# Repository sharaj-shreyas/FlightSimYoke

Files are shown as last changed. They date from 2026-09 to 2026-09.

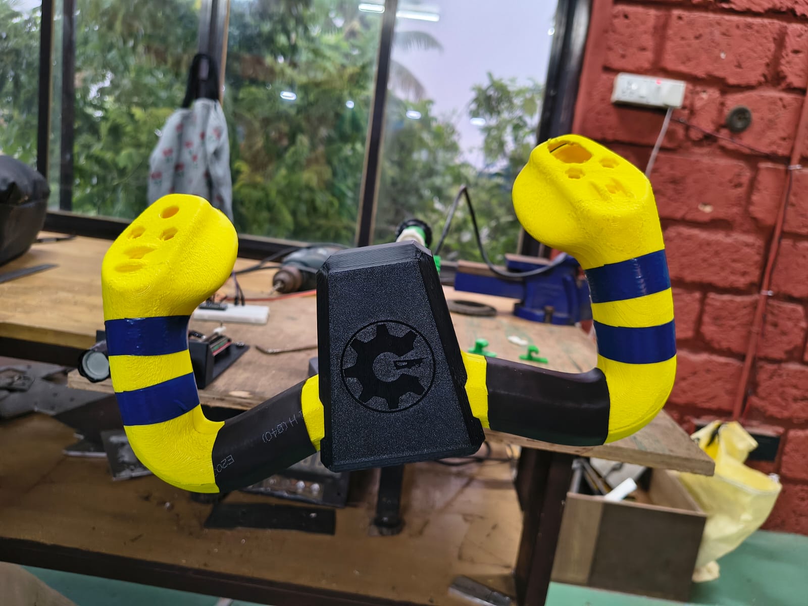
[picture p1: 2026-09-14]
img/2.jpeg

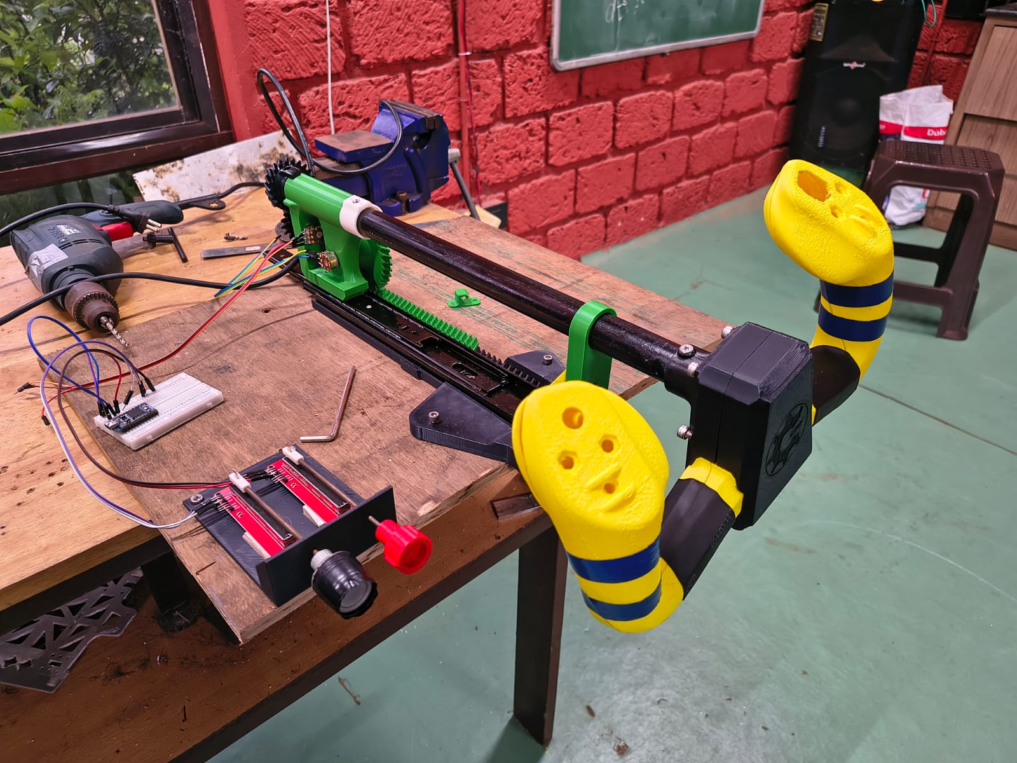
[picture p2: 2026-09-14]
img/1.jpeg

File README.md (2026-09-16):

# FlightSimYoke 
This is a flight simulator yoke and throttle mixture that we designed and built from scratch with some design references from the CadetYoke project.

## Credits - Makerspace Batch of '26
-> Sharaj Shreyas:- Hardware Primary, CAD Primary, Makerspace President, shopping bargainer.
-> Sanath Sanjay Shet:- Software Primary, Slay Queen.
-> Lauren Marian Patrao:- Math genius, emotional support 🤣.

## Read this upto the technical details warning Before doing anything silly with our Project!

## More about the project 
This project started after our JEE exams.. when we were practically jobless and had nothing to do. We came across CadetYokeV2 (https://www.thingiverse.com/thing:4884092), and we knew we had to build this. We started off with a plan to build 4 of these, 1 being the initial version, and then one V2 for the club and one each for Sanath and me. But that did not happen ofc.  We also wanted to build rudder pedal and make the yoke removable and have a steering wheel extension asw but then i had to leave to Gandhinagar 🥀.
When we started printing the files on the bamboo.. we had our first regret. We printed it in the worst setting and worst filament to save time and money but trust me guys, it's not worth it. Anyway, we proceeded with all the building part, and that's when we realised that the printed parts had also warped cuz idiotic me didnt put any supports and rafts. Second regret we went to a hardware shop to buy pipe for the shaft cuz that dude is laurens something and we were expecting a discount. That mf robbed us 🥀. Printing took so much time that we fixed the Creality printer as well, so that we could get things done faster. Fixing the duelmaze and the radiotelescope had already taken too much time and we were far behind schedule. Lauren still had hope that we would finish the pedals, but sadly, we couldn't. Hoping further batches come and fix that as well. 

### Technical Details Warning - Pay attention if you're in charge of setting this up.

## Initial Hardware Setup
1. Firstly, all connections to the Pro Micro need to be made. Check the code for connections
2. Connect the Pro Micro to your computer.
3. Tighten the screws under the green part that slides on the telescopic rails.

## Initial Software setup
1. Once plugged in, the device should show up in Device Manager as a human interface device, specifically a joystick. Do the config for the joystick and choose the axis properly.
2. We don't have a rudder channel, so u can use two keys for now. Or be an expert pilot like me 😜.
3. On MSFS, map the channels to the respective axis and set expo settings (optional).
4. enjoy!

## CAD issues 
1. The throttle and mixture knobs base isn't designed well.. better to redesign
2. Use the adapter for rods given as a separate file (not the one in the throttle+mix file).
3. Try to use exact screws wherever mentioned (Sanath fucking shet just didn't go according to my design)
4. Don't print everything randomly. I have uploaded CAD files with all parts (some are unnecessary and were used for design reference). Check what parts are necessary and then print accordingly. The CAD files also have their edit history with them. Make the best use of them to suit your hardware.

##  Troubleshooting
1. Something broke?? go kys
2. No response usually means loose wires or you've fried the board.
3. Not detecting as a HID device - figure out the driver stuff.
4. If any axis moves backwards in Windows USB Game Controllers (joy.cpl) or MSFS/X-Plane, invert the read value in code (like - FlightYoke.setYAxis(1023 - pitchVal);).

## Requests:
1. Build rudder pedals.
2. Don't break it, the setup is kinda delicate.
3. Think of meaningful upgrades.

## Contributing:
To contribute, make sure to open a branch first, commit there, and then we will review it and merge your pull request.

# Current:
The current code is very basic, and not intended to be the final version as of now, it will, however, be modified over the coming days and will slowly turn into the main source code, after lots of flightsim ofc.

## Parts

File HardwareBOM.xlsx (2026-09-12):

No. | Part | Qty. | Link
1 | M3x16 | 15 | https://onlyscrews.in/products/m3-x-16mm-hex-allen-socket-head-high-tensile12-9-black-anodized-screw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
2 | M3x45 | 8 | https://onlyscrews.in/products/m3-x-45mm-hex-allen-socket-head-high-tensile12-9-black-oxide-screw-dia-3mm-length-45mm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
3 | M5X16 | 8 | https://onlyscrews.in/products/hex-allen-socket-head-m5-x-20?variant=48590709195065
4 | M5X25 | 15 | https://onlyscrews.in/products/m5-x-25mm-hex-allen-socket-head-ss-304-screw?variant=49091478389049
5 | M5X45 | 12 | https://onlyscrews.in/products/m5-x-45mm-hex-allen-socket-head-high-tensile12-9-black-oxide-screw-dia-5mm-length-45mm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
6 | M5X60 | 12 | https://onlyscrews.in/products/m5-x-60mm-hex-allen-socket-head-ss-304-screw-dia-5mm-length-60mm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
7 | M6X20 | 6 | https://onlyscrews.in/products/m6-x-20mm-hex-allen-socket-head-high-tensile12-9-black-oxide-screw-dia-6mm-length-20mm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
8 | M6x45 | 5 | https://onlyscrews.in/products/m6-x-45mm-hex-allen-socket-head-high-tensile12-9-black-oxide-screw-dia-6mm-length-45mm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
9 | M6x120 | 5 | Local
10 | M10x25 | 2 | https://onlyscrews.in/products/m10-x-25mm-hex-allen-socket-head-high-tensile12-9-black-oxide-screw-dia-10mm-length-25mm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
11 | Bearing 625ZZ | 10 | https://onlyscrews.in/products/625-zz-deep-groove-ball-bearing-8x22x7
12 | M3 insert | 15 | https://onlyscrews.in/products/m3-x-5mm-3d-printing-brass-threaded-inserts-dia-3mm-length-5mm
13 | M5 insert | 25 | https://onlyscrews.in/products/m5-x-6mm-brass-threaded-inserts
14 | 3.2 Washers | 30 | http://onlyscrews.in/products/m3-washer-ss304
15 | 5.3 Washers | 30 | https://onlyscrews.in/products/m5-washer-ss304
16 | Nylon nut M3 | 40 | https://onlyscrews.in/products/m3-nyloc-nuts-ss304
17 | Nylon nut M5 | 35 | https://onlyscrews.in/products/m5-nyloc-nuts-ss304
18 | Nylon nut M6 | 15 | https://onlyscrews.in/products/m6-nyloc-nuts-ss304
19 | 608 ZZ Ball Bearing | 8 | https://onlyscrews.in/products/608-zz-deep-groove-ball-bearing-6x17x6
20 | m3X8 | 20 | https://onlyscrews.in/products/hex-allen-csk-m3-x-8-screw-pack-of-20
21 | m4X10 | 5 | https://onlyscrews.in/products/hex-allen-csk-m4-x-10-screw-pack-of-20
22 | m4 NYLOC nuts | 15 | https://onlyscrews.in/products/m4-nyloc-nuts-ss304
23 | M3x8 threaded insert | 10 | https://onlyscrews.in/products/m3-x-8mm-brass-threaded-inserts
24 | m2x4 | 6 | https://onlyscrews.in/products/m2-x-4mm-phillips-round-head-laptop-screw
25 | M2x3 threaded insert | 6 | https://onlyscrews.in/products/m2-x-3mm-brass-threaded-inserts
26 | M3x4 | 10 | https://onlyscrews.in/products/m3-x-8mm-hex-allen-socket-head-high-tensile12-9-black-oxide-screw-dia-3mm-length-8mm
27 | M3x4 threaded insert | 10 | https://onlyscrews.in/products/m4-x-4mm-brass-threaded-inserts
28 | M3x3 threaded insert | 10 | https://onlyscrews.in/products/m3-x-3mm-brass-threaded-inserts
29 | m4x30 | 5 | https://onlyscrews.in/products/m4-x-30mm-hex-allen-csk-ss-304-screw
30 | m3x5 | 15 | https://onlyscrews.in/products/m3-x-5mm-phillips-pan-head-ss-304-screw-dia-3mm-length-5mm
 | M3 Nut | 5
 | M3x8 | 11
 | M4x10 | 3
 | M4 Nut | 8
 | M3x8 Threaded Insert | 6
 | M4x18 | 2
 | M2x4 | 2
 | M2x3 Threaded Insert | 2
 | M3x4 | 6
 | M3x4 Threaded Insert | 8
 | M3x3 Threaded Insert | 6
 | M4x30 | 3
 | M3x5 | 12

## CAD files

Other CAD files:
CAD/Band hook.f3d
CAD/Custom_Guide.f3d
CAD/Throttle+MIX/Throttle +MIX.f3d
CAD/Throttle+MIX/adapter.f3d

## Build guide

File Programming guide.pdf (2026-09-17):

## DuelMaze Programming Guide

### Objectives:

This guide aims to help you with the syntax of C++, and how to program the components being used in the project. These components include the servos, I2C LCD, and the Arduino itself.

### How to use this guide:

The main objective of this guide is to help the members understand what they are going to be working with, and to reduce the time spent on teaching, and utilize it to actually work on the project. Whenever you are stuck on a problem, use this guide first to try and understand the correct way of doing things, and THEN ask one of the UC’s, or your Team Members.

## 1. C++ Syntax:

The language used in Arduino programming is CPP, albeit a more limited version of it. For the scope of this project, we do not need very complicated C++ knowledge. Read the example below to understand how to do basic programming tasks in C++.

### 1.1 Variables and Data Types:

Variables are by far one of the most important parts of programming. Make sure to learn how to use Data Types and variables, because they are fundamental to being able to participate.

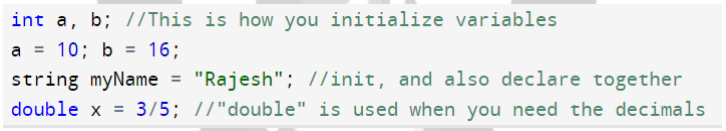
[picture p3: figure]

Notice how in C++, unlike Python, the variables’ data types need to be declared. Also, the variables need not be assigned a value while declaring them, that can be done later as well, as in the case of variables ‘a’ and ‘b’ in our case here. However, the variable ‘myName’ has been declared and given a value at the same time as you can see.

The data type int is used when we want to store an integer(lol), and the string data type is used when we need to store letters, words, etc. the double type, called “floating point” in other languages, is used to store numbers with decimal points in them.
These data types are very important, and will be used during the course of the project.

### 1.2 Flow of Control:

Flow of control is another important aspect of programming, and is almost always the backbone of the program. There are mainly 2 types of flow, namely decisions(if, else) and loops(while, for).

### 1.2.1 IF, ELSE:

If and else statements are used when there is a need to execute only parts of the program, depending on the condition specified. An example is given below:

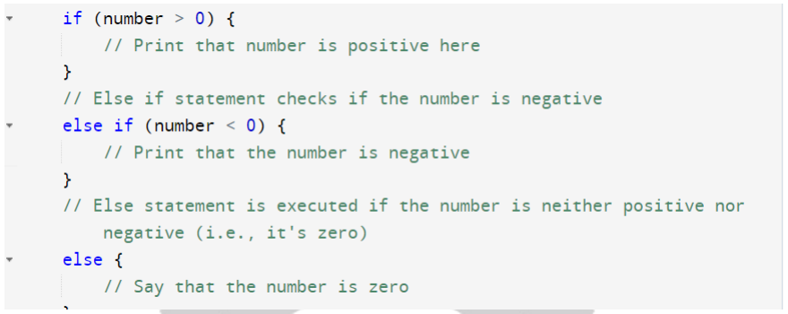
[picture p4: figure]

In this case, we have some variable, number. It’s not necessary to know where this variable comes from, since this is just an example. The code is self explanatory, because of the comments. Now, lets move on to Looping.

### 1.2.2 Looping:

Loops are similar to if and else statements, in the sense that they also check for a condition. The only difference is that instead of executing that particular block of code just once, they do it again and again, until that condition becomes false. There are mainly 3 types of loops in C++, but we’ll only be looking at 2, which are used in all languages. They are: while loops and for loops.

### 1.2.2.1 For loops:

For loops are used, when we know exactly how many times we want to repeat a block of code, or when we want to iterate through a list(this will be discussed later). For example, here, this block of code prints numbers all the way from 1 to 5.

In the code here, notice the syntax of the for loop. First, we declare a control variable, called i, and we give it a value of 1. Then, we tell the loop the condition. In this case, the condition is that i must be less than or equal to 5. The last part is incrementing the value of i. So, in the first iteration(iteration means the same as repetition), the value of i is 1. In the second iteration, it is 2, and so on, until it becomes 5. When the value of i becomes 6, the condition we specified, becomes false, and the loop stops. This is how the output looks.

### 1.2.2.2 While Loops:

While loops are similar to For Loops, in the sense that the code executes based on a control variable, say i. The loop executes till the condition specified is true, and this can be ANY condition, unlike in a for loop, where it only executes based on value. Unlike a for loop, the value of the control variable in this case does not need to change every iteration. This will be more useful in complex programs. Here’s the same program we saw earlier, but written using a while loop.

Now, notice how the syntax is different from a for loop. We declare a variable, i, but outside the loop, and then we only check for the condition when writing the loop. Now, another important thing to notice is that we change(in this case, we are incrementing) the value of i, INSIDE the body of the loop. It is VERY important to make sure that this value changes, orelse the loop will become infinite, which we don't want.

Alright! You’ve just learnt the basics of C++ programming! There are many more topics left, such as arrays, etc. But they’ll be taught to you during the sessions. Now, lets move on to the libraries that we’ll be using in arduino programming, and the structure of an arduino program.

## 2. Arduino Programming:

This second section will cover the Arduino program structure, and the 2 libraries that we’ll be using, which is the LCD-I2C, and the Servo.

### 2.1 Arduino Program Structure:

The basics of arduino programming were taught to you, but lets recap:

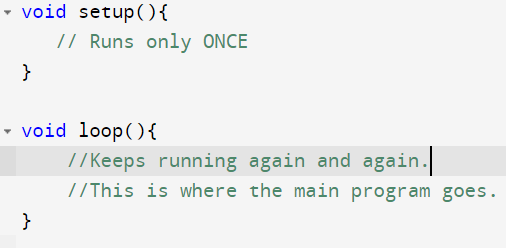
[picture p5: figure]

### 2.2 Servos:

Most of you have already worked with servos in our previous makerspace sessions. In this part, lets go over how to actually turn a servo.

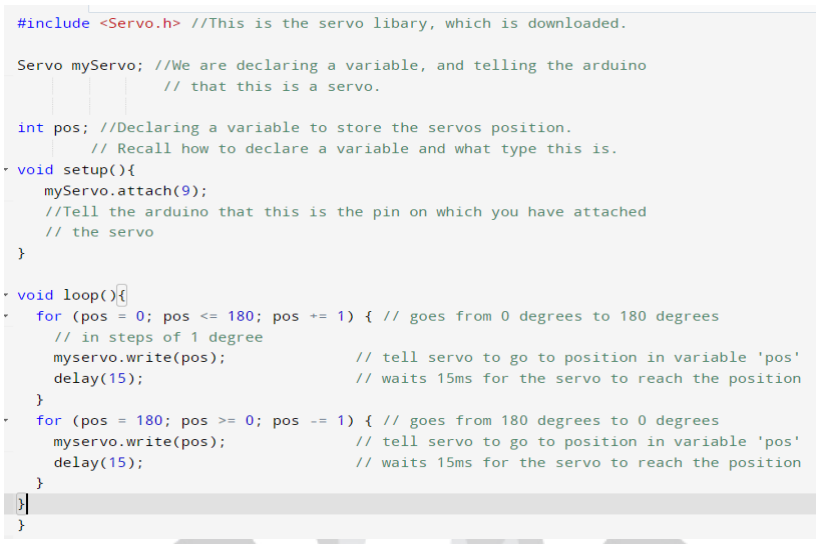
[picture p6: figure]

You all must have already written this program in your makers sessions. In case you ever forget how to use a servo, please refer to this code snippet, and see what you missed.

### 2.3 LCD I2C:

The LCD I2C has already been discussed in the session. This is an example code, please refer to it in case you need to use the LCD.

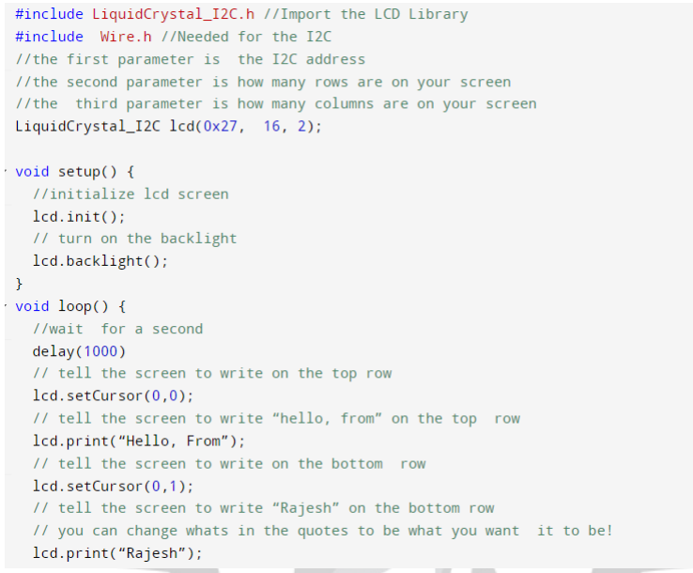
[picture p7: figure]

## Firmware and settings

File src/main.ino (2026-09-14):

#include <Joystick.h>

//def
const int PIN_PITCH    = A0; // Elevator (Y-Axis)
const int PIN_ROLL     = A1; // Aileron  (X-Axis)
const int PIN_THROTTLE = A2; // Throttle
const int PIN_MIXTURE  = A3; // Mixture 

// Initialize Joystick HID Profile
// Joystick(hidReportId, joystickType, buttonCount, hatSwitchCount,
//          includeXAxis, includeYAxis, includeZAxis,
//          includeRxAxis, includeRyAxis, includeRzAxis,
//          includeRudder, includeThrottle, includeAccelerator,
//          includeBrake, includeSteering)
Joystick_ FlightYoke(
  JOYSTICK_DEFAULT_REPORT_ID, 
  JOYSTICK_TYPE_JOYSTICK, 
  0, 0,                   // 0 Buttons, 0 Hat switches
  true,  true,  false,    // X (Roll), Y (Pitch), Z
  false, false, false,    // Rx, Ry, Rz
  false, true,  false,    // Rudder, Throttle, Accelerator
  true,  false            // Brake (used for 2nd slider/mixture), Steering
);

void setup() {
  // Set ADC range (0 to 1023) to match internal ADC resolution
  FlightYoke.setXAxisRange(0, 1023);
  FlightYoke.setYAxisRange(0, 1023);
  FlightYoke.setThrottleRange(0, 1023);
  FlightYoke.setBrakeRange(0, 1023);

  FlightYoke.begin();
}

void loop() {
  //analogread
  int pitchVal    = analogRead(PIN_PITCH);
  int rollVal     = analogRead(PIN_ROLL);
  int throttleVal = analogRead(PIN_THROTTLE);
  int mixtureVal  = analogRead(PIN_MIXTURE);

  // If an axis moves in reverse, invert it using: (1023 - val)
  FlightYoke.setYAxis(pitchVal);
  FlightYoke.setXAxis(rollVal);
  FlightYoke.setThrottle(throttleVal);
  FlightYoke.setBrake(mixtureVal);

  delay(10); // delay
}

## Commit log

2026-09-12 Added hardwareBOM
    [HardwareBOM.xlsx]
2026-09-12 cad section
    copilot stop
2026-09-12 added all CAD files
    [Band hook.f3d, Custom_Guide.f3d, Throttle +MIX.f3d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]
